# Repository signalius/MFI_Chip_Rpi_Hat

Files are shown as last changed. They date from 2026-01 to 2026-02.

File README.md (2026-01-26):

## MFI Raspberry Pi Hat
This Raspberry Pi HAT allows you to work with MFI chips with the symbols MFI343S00177 and MFI337S3959. 
Additionally, it has a USB C power in connector because USB C from Raspberry Pi may be needed as a USB OTG port.

* Tested on: Raspberry 5 and Zero 2W
* Interface: I2C

## Sample cert

Convert string hex to binary file
```bash
echo "3082025b06092a86...." | xxd -r -p > cert.bin
```

Decode it
```bash
openssl pkcs7 -inform DER -in cert.bin -print_certs -text -noout
```

Result
```bash
Certificate:
    Data:
        Version: 3 (0x2)
        Serial Number:
            22:22:aa:15:08:17:aa:06:aa:90:07:aa:16:78:09
        Signature Algorithm: sha1WithRSAEncryption
        Issuer: C=US, O=Apple Inc., OU=Apple Certification Authority, CN=Apple iPod Accessories Certification Authority
        Validity
            Not Before: Aug 17 20:46:29 2015 GMT
            Not After : Feb 14 22:18:08 2022 GMT
        Subject: C=US, O=Apple Inc., OU=Apple iPod Accessories, CN=IPA_2222AA150817AA06AA9007AA167809
        Subject Public Key Info:
            Public Key Algorithm: rsaEncryption
                Public-Key: (1024 bit)
                Modulus:
                    00:b7:dd:d3:81:e7:38:97:7c:06:72:91:3d:6c:4a:
                    cf:d0:01:d1:af:30:06:9c:05:67:84:76:da:bc:d5:
                    ee:94:8d:c4:63:11:3c:95:67:17:ff:a9:48:85:b8:
                    34:02:6e:8c:54:71:13:a7:c0:ad:11:39:86:4a:a1:
                    df:f3:45:d5:27:d5:e4:b2:b4:d0:61:ab:fb:31:7d:
                    f2:7c:c8:27:45:cd:d6:61:8d:88:d3:9f:43:a6:91:
                    3c:ad:ad:c5:1e:62:cc:61:1b:49:27:1a:10:26:a1:
                    20:14:a3:6b:58:62:ad:6a:bc:95:13:ac:72:38:73:
                    b2:84:e8:b6:51:a1:fa:39:2b
                Exponent: 65537 (0x10001)
        X509v3 extensions:
            X509v3 Subject Key Identifier: 
                D6:2B:D0:95:57:59:86:81:DB:D7:A0:32:75:2D:B9:A3:6E:5B:8A:38
            X509v3 Basic Constraints: critical
                CA:FALSE
            X509v3 Authority Key Identifier: 
                FF:4B:1A:43:9A:F5:19:96:AB:18:00:2B:61:C9:EE:40:9D:8E:C7:04
            X509v3 Key Usage: critical
                Digital Signature, Key Encipherment, Data Encipherment, Key Agreement
    Signature Algorithm: sha1WithRSAEncryption
    Signature Value:
        62:01:2d:2e:1b:39:ce:41:81:ea:a8:f3:07:e7:01:ee:d0:26:
```

## Schematic

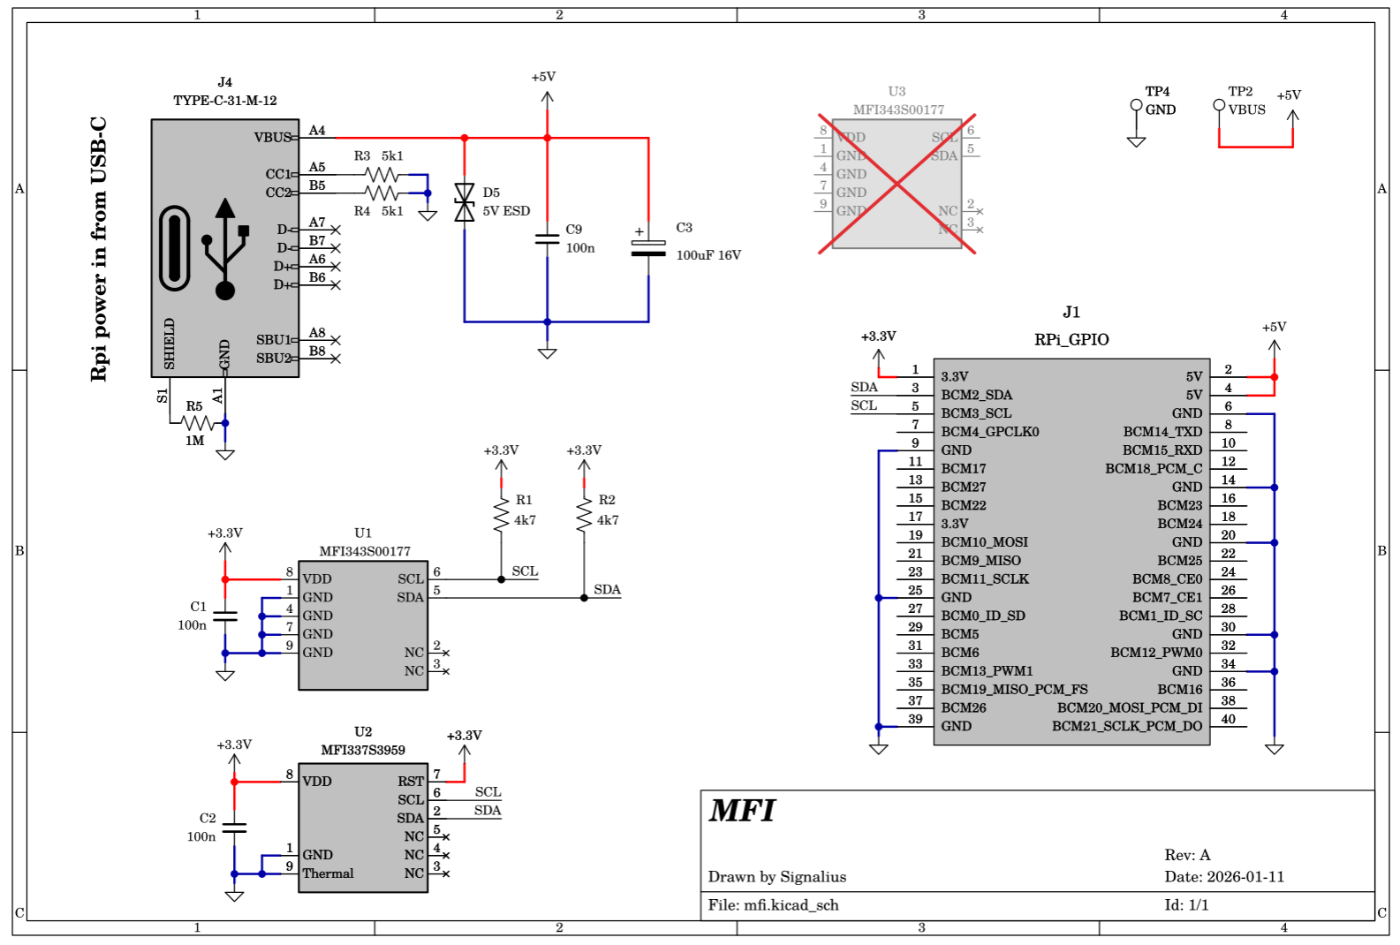
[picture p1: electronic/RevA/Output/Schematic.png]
schematic


# PCB view

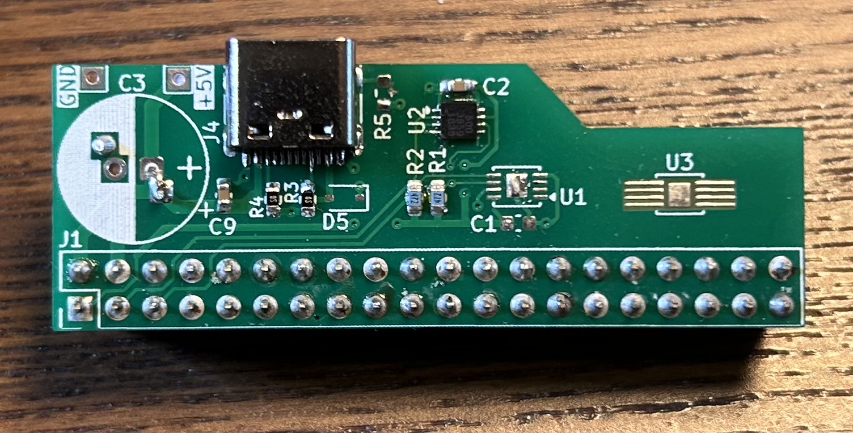
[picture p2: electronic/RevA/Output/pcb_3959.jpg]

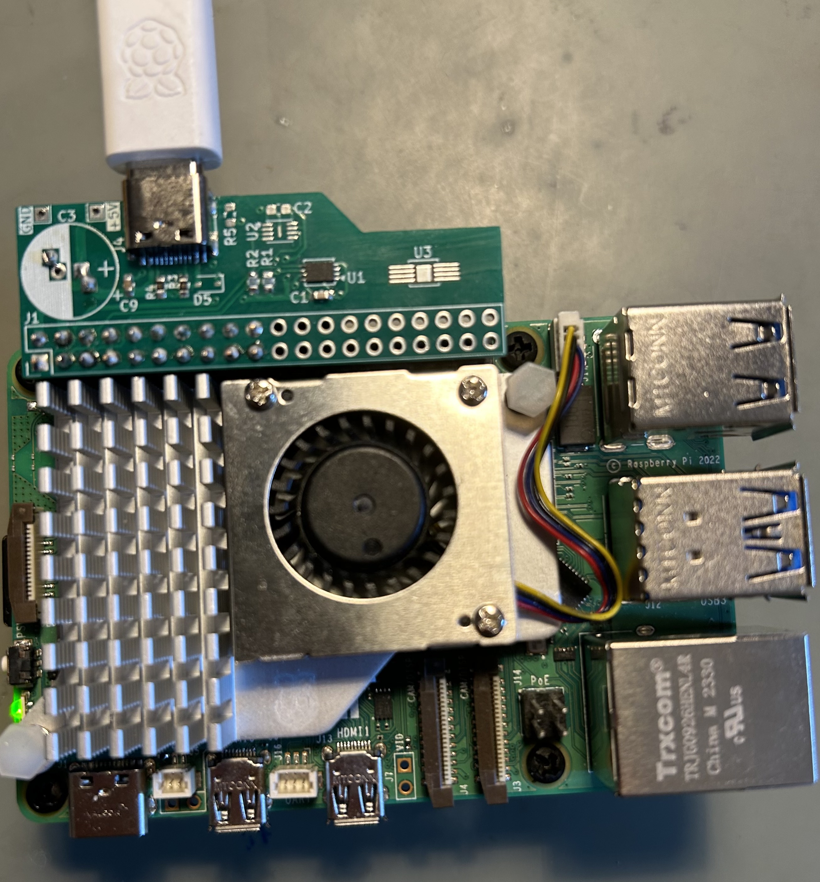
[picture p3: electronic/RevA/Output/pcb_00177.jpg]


## LICENSE
GNU General Public License v3.0

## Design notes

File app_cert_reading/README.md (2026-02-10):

## Application to read cert from MFI chip

First you have to enable i2c
```bash
raspi-config
```

To check if MFI chip is visible in RPi:
```bash
# List all i2c interfaces
i2cdetect -l 
# Check interface number 1
i2cdetect -y 1 
```

Before using, set the appropriate i2c interface and I2c address. 
The address is usually 0x10 or 0x11 and the interface is /dev/i2c-1.
Then:
```bash
python3 auth.py
```

## LICENSE
GNU General Public License v3.0

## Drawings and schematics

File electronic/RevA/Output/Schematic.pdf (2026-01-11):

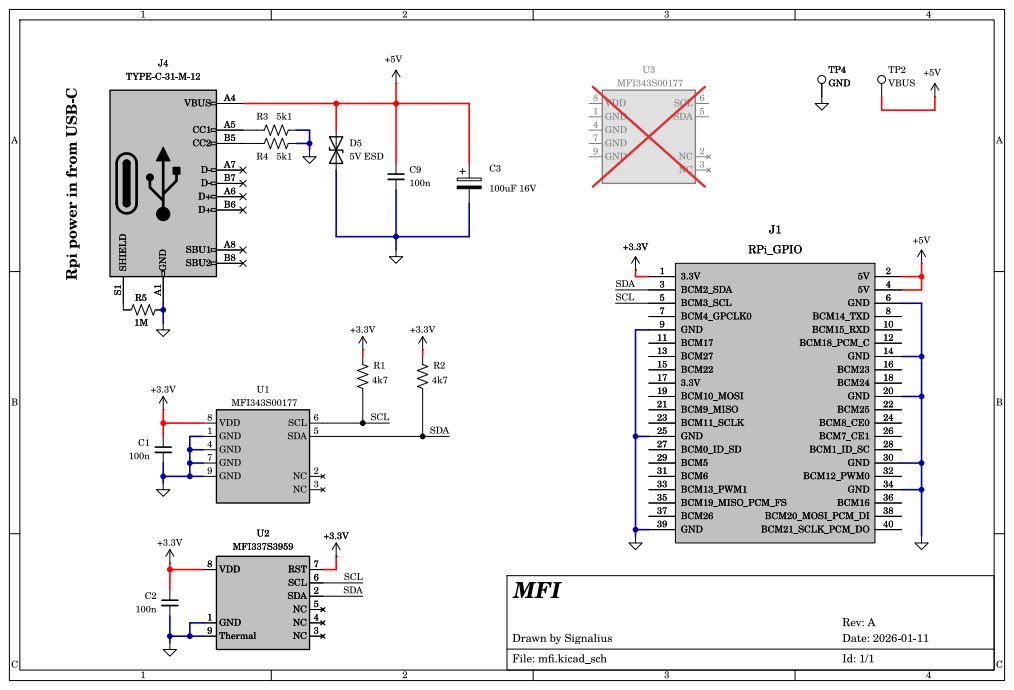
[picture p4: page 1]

SCL Rpi power in from USB-C

Id: 1/1 MFI File: mfi.kicad_sch Drawn by Signalius R2
SCL SDA

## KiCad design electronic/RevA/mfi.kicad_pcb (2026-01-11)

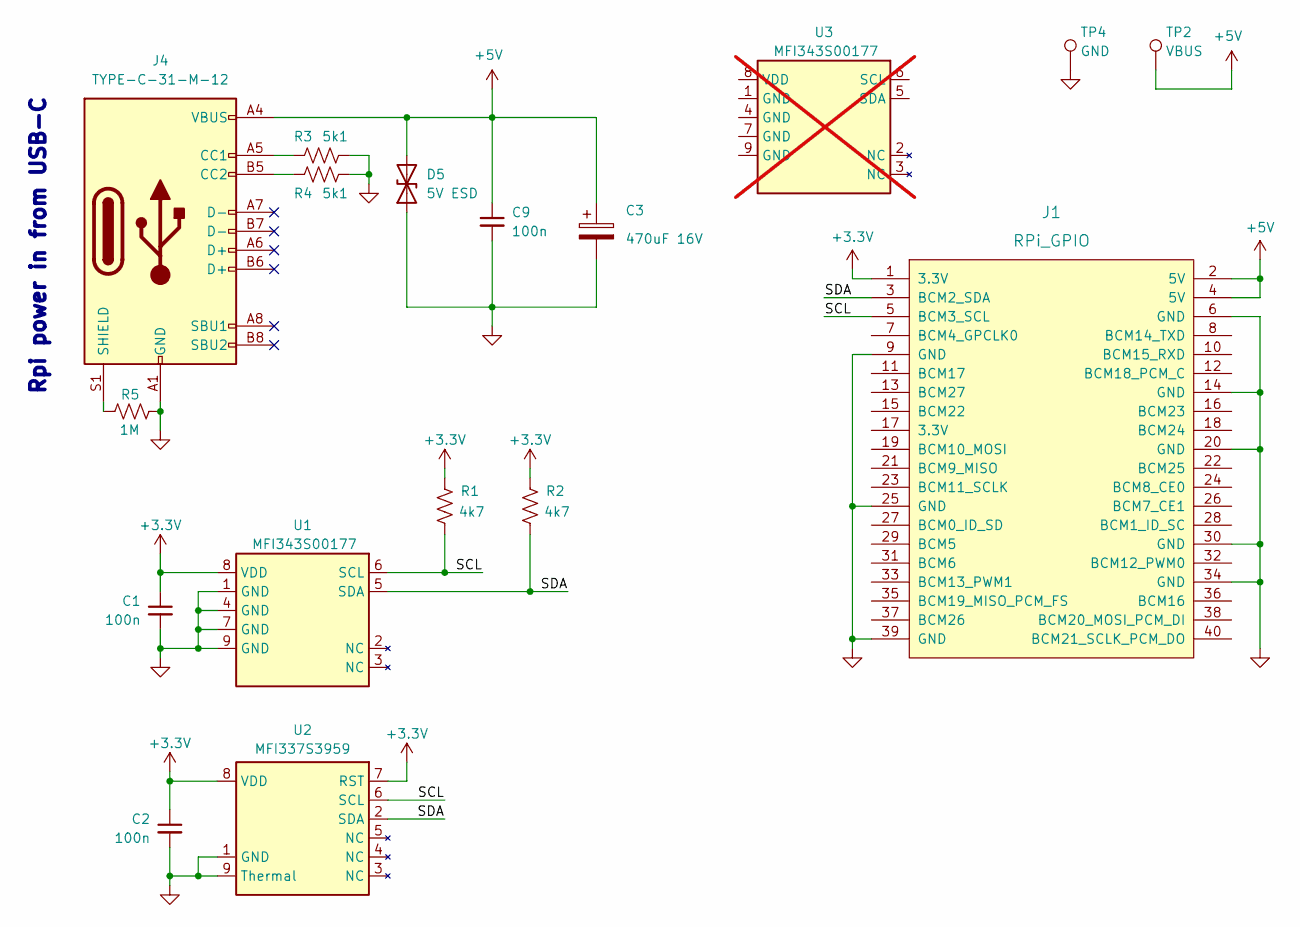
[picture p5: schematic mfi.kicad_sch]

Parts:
C1, C2, C9: 100n; C_0603_1608Metric
C3: 470uF 16V; CP_Radial_D10.0mm_P2.50mm_P5.00mm
D5: 5V ESD; D_SOD-323; MPN PESD5V0L1BA,115
J1: RPi_GPIO; PinHeader_2x20_P2.54mm_Vertical
J4: TYPE-C-31-M-12; USB_C_Receptacle_HRO_TYPE-C-31-M-12; MPN TYPE-C-31-M-12
R1, R2: 4k7; R_0603_1608Metric
R3, R4: 5k1; R_0603_1608Metric
R5: 1M; R_0603_1608Metric
TP2: VBUS; TestPoint_THTPad_1.5x1.5mm_Drill0.7mm
TP4: GND; TestPoint_THTPad_1.5x1.5mm_Drill0.7mm
U1: MFI343S00177; MFI_UDFN-8-1EP_2x3mm_P0.5mm
U2: MFI337S3959; MFI_WSON-8-1EP_2.5x2.5mm_P0.5mm
U3: MFI343S00177; MFI_UDFN-8-1EP_2x3mm_P0.5mm; not fitted

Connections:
+3.3V: C1.1, C2.1, J1.1 (3.3V), R1.1, R2.1, U1.8 (VDD), U2.7 (RST), U2.8 (VDD)
+5V: C3.1, C9.1, D5.2 (A2), J1.2 (5V), J1.4 (5V), J4.A4 (VBUS), J4.A9 (VBUS), J4.B4 (VBUS), J4.B9 (VBUS), TP2.1
/SCL: J1.5 (BCM3_SCL), R1.2, U1.6 (SCL), U2.6 (SCL)
/SDA: J1.3 (BCM2_SDA), R2.2, U1.5 (SDA), U2.2 (SDA)
GND: C1.2, C2.2, C3.2, C9.2, D5.1 (A1), J1.6 (GND), J1.9 (GND), J1.14 (GND), J1.20 (GND), J1.25 (GND), J1.30 (GND), J1.34 (GND), J1.39 (GND), J4.A1 (GND), J4.A12 (GND), J4.B1 (GND), J4.B12 (GND), R3.2, R4.2, R5.2, TP4.1, U1.1 (GND), U1.4 (GND), U1.7 (GND), U1.9 (GND), U2.1 (GND), U2.9 (Thermal)
unnamed: J4.A5 (CC1), R3.1
unnamed: J4.B5 (CC2), R4.1
unnamed: J4.S1 (SHIELD), R5.1

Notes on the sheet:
Rpi power in from USB-C

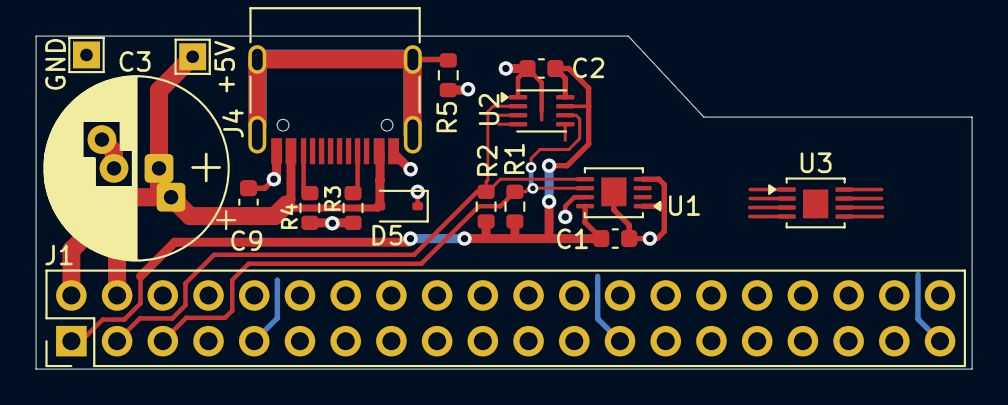
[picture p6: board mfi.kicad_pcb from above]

Board: 2 copper layers, 52.0 x 18.5 mm, 17 parts (0 on the bottom side), 8 nets.

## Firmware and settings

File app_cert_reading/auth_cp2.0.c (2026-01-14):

#include <stdio.h>
#include <stdlib.h>
#include <linux/i2c-dev.h>
#include <fcntl.h>
#include <assert.h>
#include <stdint.h>
#include <string.h>
#include <sys/ioctl.h>
#include <unistd.h>
#include <glib.h>
#include <sys/socket.h>
#include <arpa/inet.h>

#define LOG(fmt, ...) \
    fprintf(stderr, "%s:%d:%s: " fmt "\n", __FILE__, __LINE__, __func__, ##__VA_ARGS__)


#define I2C_BUS             "/dev/i2c-1"

struct i2c_msg {
	__u16 addr;							/* slave address			*/
	unsigned short flags;
#define I2C_M_TEN			0x10		/* we have a ten bit chip address	*/
#define I2C_M_RD			0x01
#define I2C_M_NOSTART		0x4000
#define I2C_M_REV_DIR_ADDR	0x2000
#define I2C_M_IGNORE_NAK	0x1000
#define I2C_M_NO_RD_ACK		0x0800
	short len;							/* msg length				*/
	char *buf;							/* pointer to msg data			*/
};

#define I2C_DEV_ADDR	    0x10
#define I2C_RETRY_COUNT	    100

gboolean iAP2I2cReadBlock( int fd, uint8_t reg, uint8_t * data, int16_t len )
{
	struct i2c_rdwr_ioctl_data _data;
	struct i2c_msg _msg;
	int _retry	=	0, _len;

	_data.nmsgs	=	1;
	_data.msgs	=	&_msg;

	_data.msgs[0].addr	=	I2C_DEV_ADDR;
	_data.msgs[0].flags	=	0;
	_data.msgs[0].len	=	1;
	_data.msgs[0].buf	=	&reg;

	while( ioctl( fd, I2C_RDWR, ( unsigned long )&_data ) < 0 )
	{
		usleep( 10000 );                          /* Waiting for device response */

		_retry	++;
		if( _retry	> I2C_RETRY_COUNT )
			break;
	}

	if( _retry > I2C_RETRY_COUNT )
	{
		perror( "iAP2I2cReadBlock write" );

		return FALSE;
	}

	_retry	=	0;

	_data.msgs[0].addr	=	I2C_DEV_ADDR;
	_data.msgs[0].flags	=	I2C_M_RD;
	_data.msgs[0].len	=	len;
	_data.msgs[0].buf	=	data;

	while(( _len = ioctl( fd, I2C_RDWR, ( unsigned long )&_data )) < 0 )
	{
		usleep( 10000 );                          /* Waiting for device response */

		_retry	++;
		if( _retry	> I2C_RETRY_COUNT )
			break;
	}

	if( _retry > I2C_RETRY_COUNT )
	{
		perror( "iAP2I2cReadBlock read" );

		return FALSE;
	}

	return TRUE;
}

gboolean iAP2I2cWriteBlock( int fd, uint8_t reg, uint8_t * data, int16_t len )
{
	struct i2c_rdwr_ioctl_data _data;
	struct i2c_msg _msg;
	uint8_t _buf[ 1 + len ];
	int _retry	=	0;

	_data.nmsgs	=	1;
	_data.msgs	=	&_msg;

	_buf[0]	=	reg;
	memcpy( _buf + 1, data, len );

	_data.msgs[0].addr	=	I2C_DEV_ADDR;
	_data.msgs[0].flags	=	0;
	_data.msgs[0].len	=	1 + len;
	_data.msgs[0].buf	=	_buf;

	while( ioctl( fd, I2C_RDWR, ( unsigned long )&_data ) < 0 )
	{
		usleep( 10000 );                            /* Waiting for device response */

		_retry	++;
		if( _retry	> I2C_RETRY_COUNT )
			break;
	}

	if( _retry > I2C_RETRY_COUNT )
	{
		perror( "iAP2I2cWriteBlock write" );

		return FALSE;
	}

	return TRUE;
}
static int fd	=	0;
/* 
 * ===  FUNCTION  ======================================================================
 *         Name:  iAP2AuthReadCertData
 *  Description:  
 * =====================================================================================
 */
int16_t iAP2AuthReadCertData( uint8_t ** data )
{
	static uint8_t * certData	=	NULL;
	static int16_t certLen	=	0;
	uint8_t _buf[2];
	int i;

	if( fd == 0 )
	{
		fd	=	open( I2C_BUS, O_RDWR );

		g_assert( fd > 0 );
	}

	if( certData == NULL )
	{
		g_assert( iAP2I2cReadBlock( fd, 0x30, _buf, 2 ));

		certLen	=	_buf[0] << 8 | _buf[1];
		certData	=	g_malloc0( certLen );

		for( i = 0; i < certLen / 128; i ++ )
		{
			iAP2I2cReadBlock( fd, 0x31 + i, certData + i * 128, 128 );
		}

		if( certLen > i * 128 )
		{
			iAP2I2cReadBlock( fd, 0x31 + i, certData + i * 128, certLen - i * 128 );
		}
	}

	* data	=	certData;

	return certLen;
}		/* -----  end of function iAP2AuthReadCertData  ----- */

/* 
 * ===  FUNCTION  ======================================================================
 *         Name:  iAP2AuthWriteChallengeData
 *  Description:  
 * =====================================================================================
 */
gboolean iAP2AuthWriteChallengeData( uint8_t * data, uint16_t len )
{
	uint8_t _buf[2]	=	{0};
	gboolean _result	=	FALSE;

	if( fd == 0 )
	{
		fd	=	open( I2C_BUS, O_RDWR );

		g_assert( fd > 0 );
	}

	_buf[0]	=	len >> 8;
	_buf[1]	=	len & 0xFF;

	g_assert( iAP2I2cWriteBlock( fd, 0x20, _buf, 2 ));

	g_assert( iAP2I2cWriteBlock( fd, 0x21, data, len ));

	_buf[0]	=	1;
	g_assert( iAP2I2cWriteBlock( fd, 0x10, _buf, 1 ));

	g_assert( iAP2I2cReadBlock( fd, 0x10, _buf, 1 ));

	if( _buf[0] & 0xF0 == 0x10 )
		_result	=	TRUE;

	return _result;
}		/* -----  end of function iAP2AuthWriteChallengeData  ----- */

/* 
 * ===  FUNCTION  ======================================================================
 *         Name:  iAP2AuthReadChallengeResponse
 *  Description:  
 * =====================================================================================
 */
int16_t iAP2AuthReadChallengeResponse( uint8_t ** data )
{
	uint8_t _buf[2];
	int16_t _resLen;
	uint8_t * _data;

	g_assert( iAP2I2cReadBlock( fd, 0x11, _buf, 2 ));

	_resLen	=	_buf[0] << 8 | _buf[1];
	_data	=	g_malloc0( _resLen );

	g_assert( iAP2I2cReadBlock( fd, 0x12, _data, _resLen ));

	* data	=	_data;

	close( fd );

	fd	=	0;

	return _resLen;
}		/* -----  end of function iAP2AuthReadChallengeResponse  ----- */
/* 
 * ===  FUNCTION  ======================================================================
 *         Name:  main
 *  Description:  
 * =====================================================================================
 */
int main ( int argc, char *argv[] )
{
	int _fd, _cfd;
	struct sockaddr_in _addr, _caddr;
	socklen_t _clen;
	unsigned char _buf[1024];

	LOG("Start");
	if((_fd = socket(AF_INET, SOCK_STREAM, 0)) < 0)
	{
		perror("Socket Create");

		return 1;
	}
	LOG("Socket created with success");
		
	{	
		uint8_t * c;
		int len =	iAP2AuthReadCertData( &c );
		LOG("Cert len=%d", len);
		if(len>0) {
			for(int i=0; i<len; i+=16) {
				for(int j=0; j<16; j++) {
					printf("%02X ", c[i+j]);			
					if(j==7) printf(" ");
				}
				printf("\n");
			}
		}
	}

	memset(&_addr, 0, sizeof(struct sockaddr_in));

	_addr.sin_family	=	AF_INET;
	_addr.sin_addr.s_addr	=	htonl(INADDR_ANY);
	_addr.sin_port		=	htons(5196);

	bind(_fd, (struct sockaddr *)&_addr, sizeof(struct sockaddr_in));

	listen(_fd, 1);

	_clen	=	sizeof(struct sockaddr_in);

	while(1)
	{
		uint16_t _certLen, _resLen;
		uint8_t * _cert, * _res;

		_cfd	=	accept(_fd, (struct sockaddr *)&_caddr, &_clen);

		printf("Wait for data\n");			
		
		recv(_cfd, _buf, 50, 0);
		
		printf("Received something...\n");			

		switch(_buf[0])
		{
		case 0:
			_certLen	=	iAP2AuthReadCertData( &_cert );
			_buf[0]	=	_certLen >> 8;
			_buf[1]	=	_certLen & 0xFF;
			LOG("_certLen=%d", _certLen);

			memcpy(_buf + 2, _cert, _certLen);
			send(_cfd, _buf, _certLen + 2, 0);
			break;
		case 1:
			iAP2AuthWriteChallengeData( _buf + 3, _buf[1] << 8 | _buf[2] );

			_resLen	=	iAP2AuthReadChallengeResponse( &_res );
			LOG("_resLen=%d", _resLen);

			_buf[0]	=	_resLen >> 8;
			_buf[1]	=	_resLen & 0xFF;

			memcpy(_buf + 2, _res, _resLen);
			send(_cfd, _buf, _resLen + 2, 0);
			break;
		default:
			break;
		}

		close(_cfd);
	}

	return 0;
}				/* ----------  end of function main  ---------- */

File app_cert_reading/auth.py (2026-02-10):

#!/usr/bin/env python3
import time
from struct import Struct
import smbus2

# --- Setup ---
I2C_DEV = "/dev/i2c-1"
DEV_ADDR = 0x11


REG_STATUS        = 0x10
REG_CHAL_LEN      = 0x20
REG_CHAL_DATA     = 0x21
REG_RESP_LEN      = 0x11
REG_RESP_DATA     = 0x12
REG_CERT_LEN      = 0x30
REG_CERT_DATA     = 0x31

STATUS_BIT_SUCCESS = 0x10  
WORD_BE = Struct(">H")
CHUNK = 32                 
PAUSE_SHORT = 0.002
PAUSE_MED   = 0.02

bus = smbus2.SMBus(I2C_DEV)

def _rd(addr: int, n: int) -> bytes:
    # write pointer
    for _ in range(5):
        try:
            bus.write_byte(DEV_ADDR, addr)
            break
        except OSError:
            time.sleep(0.005)
    else:
        raise Exception(f"timeout: set pointer 0x{addr:02x}")

    time.sleep(0.005)
    for _ in range(50):
        try:
            read_msg = smbus2.i2c_msg.read(DEV_ADDR, n)
            bus.i2c_rdwr(read_msg)
            return bytes(read_msg)
        except OSError:
            time.sleep(0.01)
    raise Exception(f"timeout: read 0x{addr:02x}")

def _rd1(addr: int) -> int:
    return _rd(addr, 1)[0]

def _wr_raw(reg: int, data: bytes, pause=PAUSE_SHORT) -> None:
    for _ in range(10):
        try:
            msg = smbus2.i2c_msg.write(DEV_ADDR, bytes([reg]) + bytes(data))
            bus.i2c_rdwr(msg)
            if pause:
                time.sleep(pause)
            return
        except OSError:
            time.sleep(0.005)
    raise Exception(f"timeout: write 0x{reg:02x}")

def _wr_status(v: int) -> None:
    _wr_raw(REG_STATUS, bytes([v]))

def read_certificate() -> bytes:
    size = WORD_BE.unpack(_rd(REG_CERT_LEN, 2))[0]
    return _rd(REG_CERT_DATA, size)

def generate_challenge_response(challenge: bytes, poll_timeout_s=5.0) -> bytes:
    try:
        _wr_status(0x00)
    except Exception:
        pass
    time.sleep(PAUSE_MED)

    # len of  challenge (BE)
    _wr_raw(REG_CHAL_LEN, WORD_BE.pack(len(challenge)), pause=PAUSE_MED)

    # data if challenge – write in one transaction 
    _wr_raw(REG_CHAL_DATA, challenge, pause=PAUSE_MED)

    time.sleep(PAUSE_MED)

    # Start
    _wr_status(0x01)

    # poll status
    t0 = time.time()
    last = None
    while time.time() - t0 < poll_timeout_s:
        try:
            s = _rd1(REG_STATUS)
        except Exception:
            s = None
        if s != last:
            print("status:", hex(s) if s is not None else None)
            last = s
        if s is not None and (s & STATUS_BIT_SUCCESS):
            break
        time.sleep(0.02)
    else:
        raise Exception("timeout waiting for signature")

    # read the answer
    resp_len = WORD_BE.unpack(_rd(REG_RESP_LEN, 2))[0]
    return _rd(REG_RESP_DATA, resp_len)

if __name__ == "__main__":
    print("I2C bus:", I2C_DEV )
    print("I2C addr:", hex(DEV_ADDR) )

    cert = read_certificate()
    print("CERT", cert.hex())

    chal20 = b"12211213131231231231"  # 20 bytes for 3959
    chal32 = b"12211213131231231231456784567845"  # 32 bytes for 00177

    resp = ""

    print("Trying 20 bytes Challenge response...")
    try:
        resp = generate_challenge_response(chal20)
    except Exception as e:
        print("20 bytes challenge error: ", e)
        print("Trying 32 bytes Challenge response...")
        resp = generate_challenge_response(chal32)

    print("RESP: ", resp.hex())


	

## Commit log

2026-01-14 Add app to read cert from mfi chip
    [mfi-B_Cu.gbr, mfi-B_Mask.gbr, mfi-Edge_Cuts.gbr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]
2026-01-14 Add bom
    [mfi.kicad_sch]
2026-01-26 Add photos and new sample cert
2026-02-19 Add note to schematic
